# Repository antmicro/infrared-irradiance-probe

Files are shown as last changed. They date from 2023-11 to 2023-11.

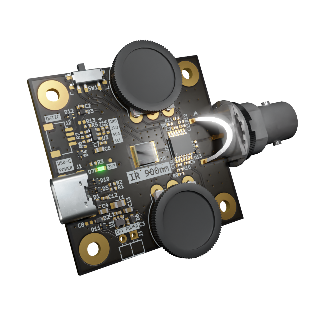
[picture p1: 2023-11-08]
assets/previews/leftT_thumbnail.png

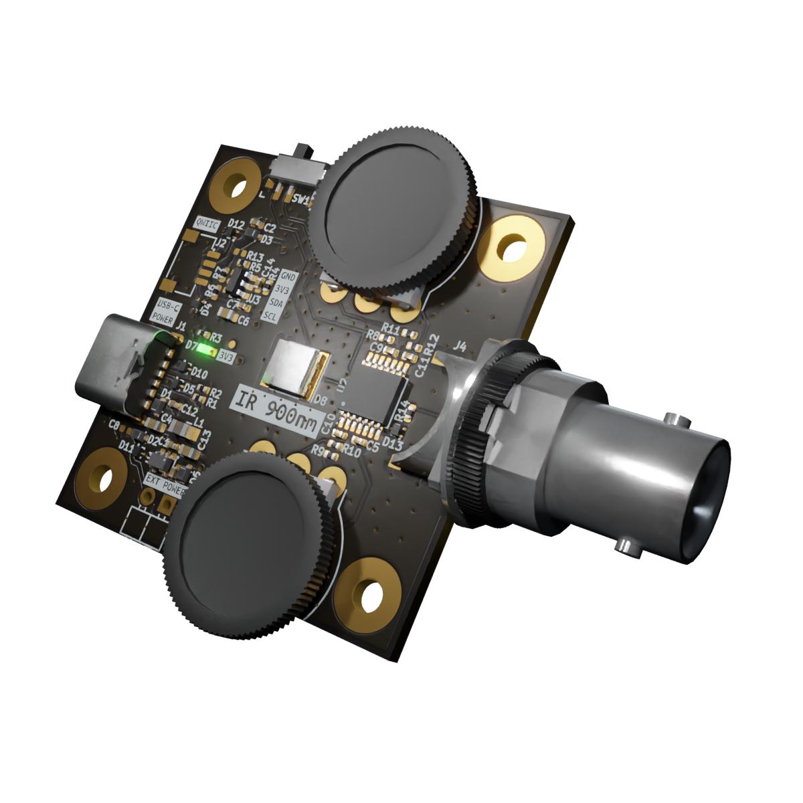
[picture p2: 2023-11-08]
assets/previews/rightT.webp

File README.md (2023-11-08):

# Infrared Irradiance Probe

Copyright (c) 2022-2023 [Antmicro](https://www.antmicro.com)

IR Irradiance Probe

## Overview

This project contains open hardware design files for a simple detector of infrared (IR) radiation.
It features two photodiodes with peak sensitivity of 900nm and 940nm, and signal-forming circuitry with adjustable gain.
The board can be used for measuring relative intensity of IR radiation and for probing dynamic illumination parameters of infrared LEDs and laser modules.

The design files were prepared in KiCad 6.x.

## Project structure 

The main directory contains KiCad PCB design files, a LICENSE and a README.
The remaining files are stored in the following directories: 

* `lib` - contains the component libraries, 
* `img` - contains graphics for this README,
* `assets` - contains visual assets used for showcasing this board on [Open Hardware Portal](https://openhardware.antmicro.com)

## Key features

* Two photodiodes for measuring IR irradiance (peak sensitivity @ 900nm for diode on top and 940nm for the bottom one)
* BNC connector for oscilloscope measurements
* Regulated sensitivity
* I2C single-channel interface for digital signal probing
* Selectable power source (USB-C / JST / external power supply)

## License

This project is licensed under the [Apache-2.0](LICENSE) license.

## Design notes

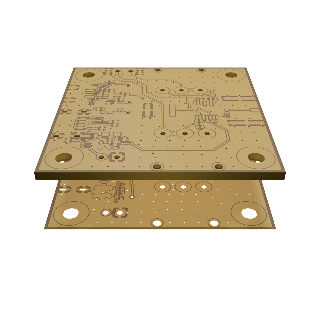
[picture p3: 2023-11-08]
assets/previews/layer1_thumbnail.webp

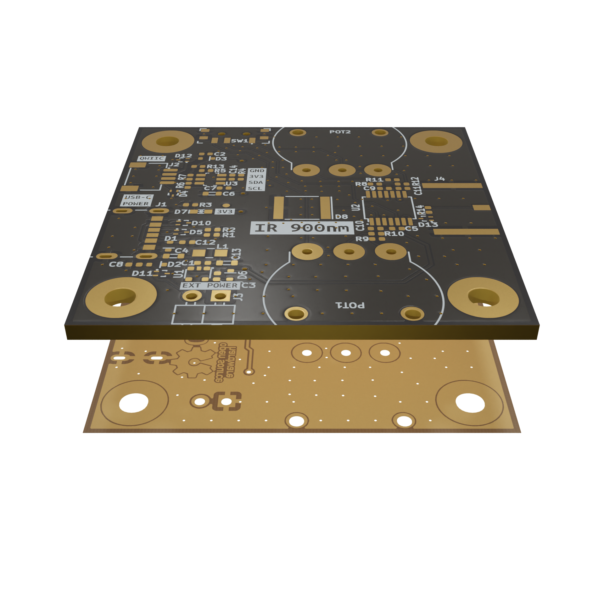
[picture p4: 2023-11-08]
assets/previews/stackup.png

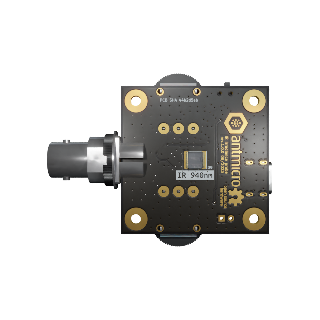
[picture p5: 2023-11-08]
assets/previews/orthoB_thumbnail.webp

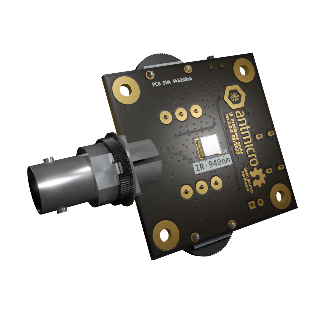
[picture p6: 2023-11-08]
assets/previews/leftB_thumbnail.png

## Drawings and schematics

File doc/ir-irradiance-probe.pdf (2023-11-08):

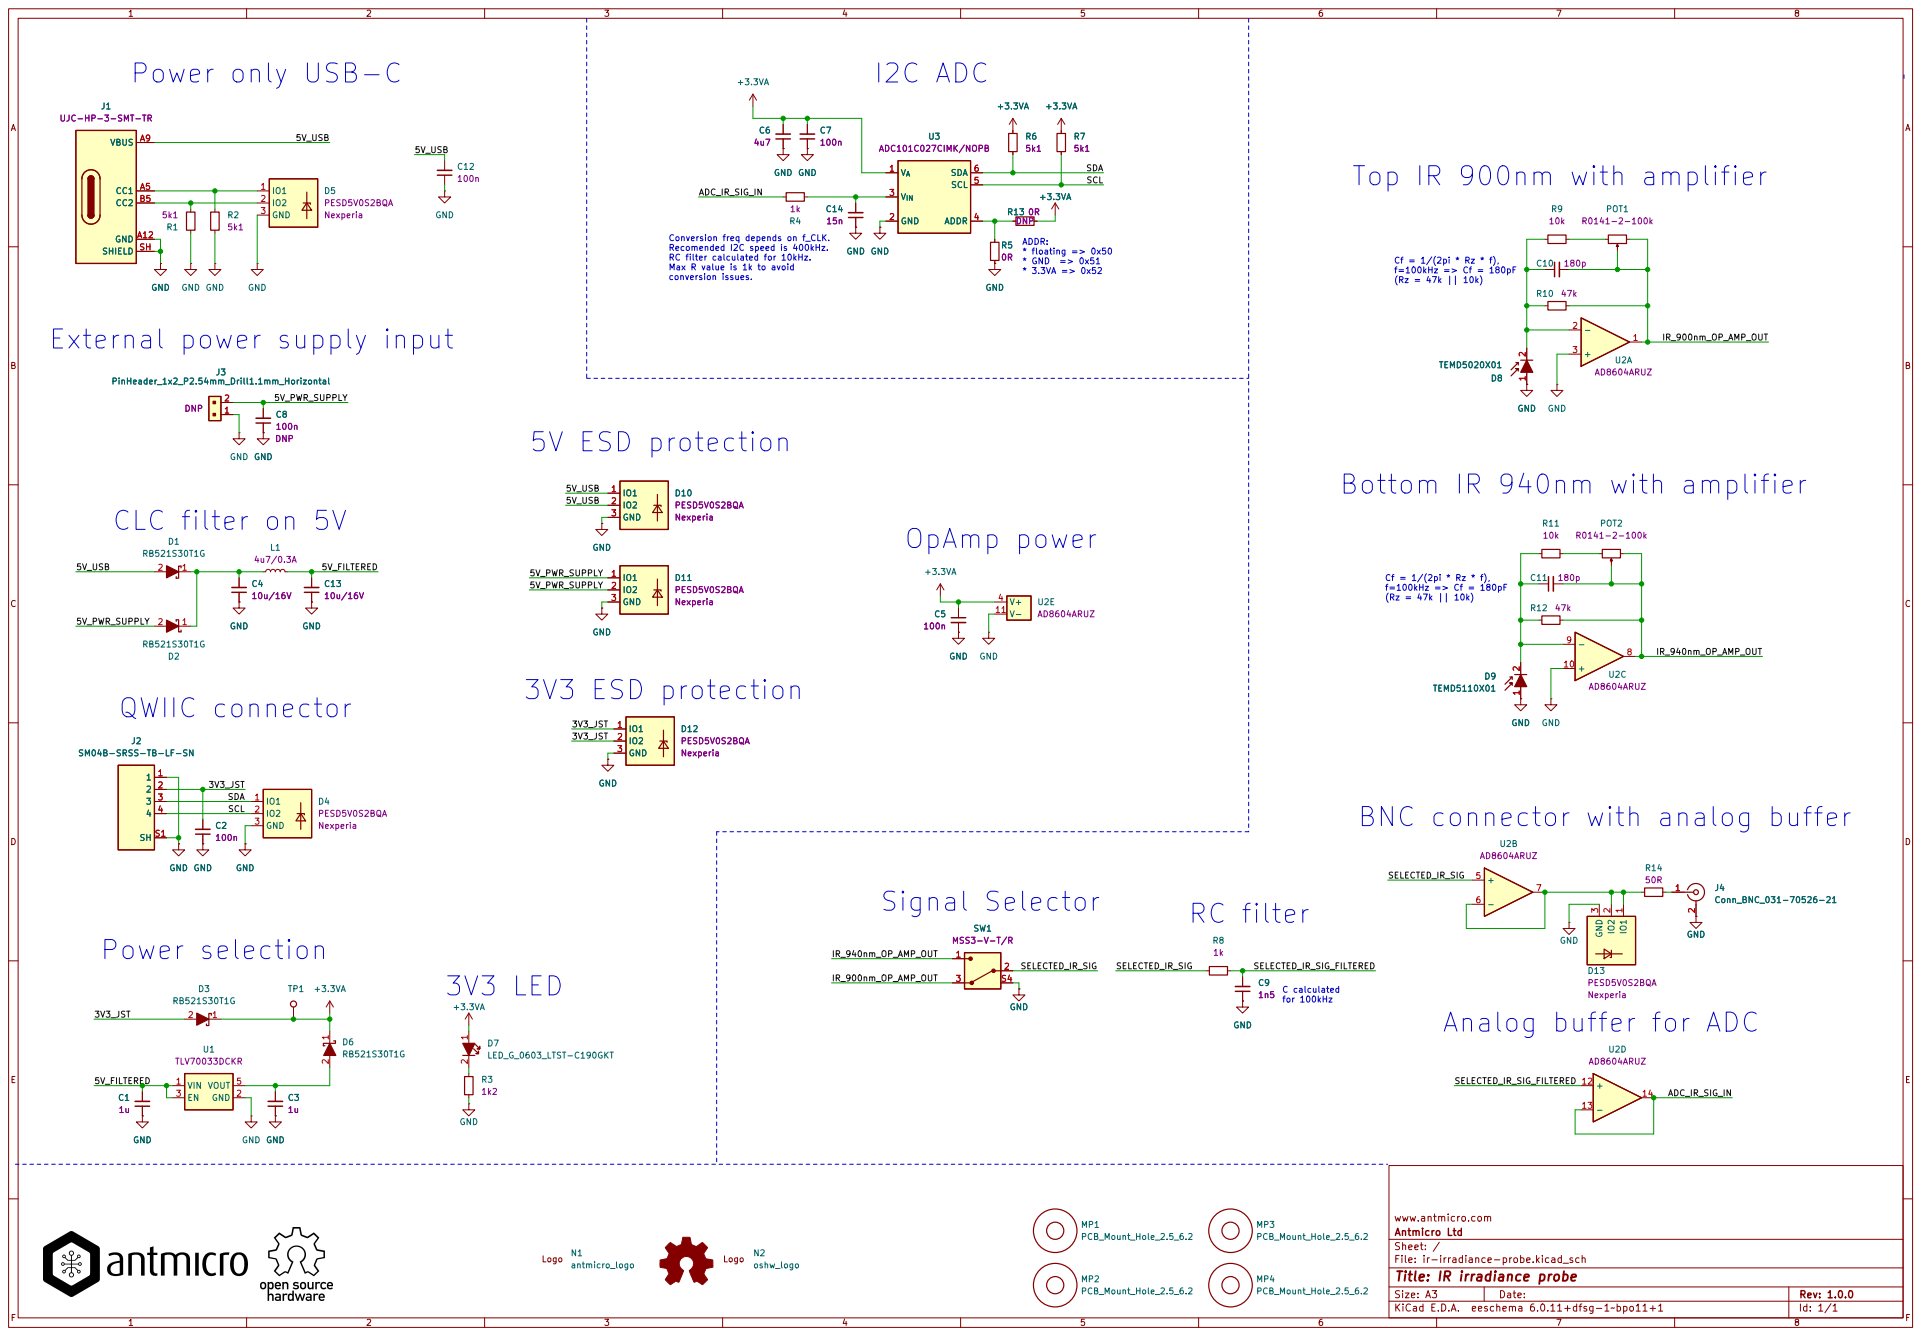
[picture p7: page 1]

J1 UJC-HP-3-SMT-TR

Top IR 900nm with amplifier

Bottom IR 940nm with amplifier

J2 SM04B-SRSS-TB-LF-SN

Id: 1/1 Title: IR irradiance probe

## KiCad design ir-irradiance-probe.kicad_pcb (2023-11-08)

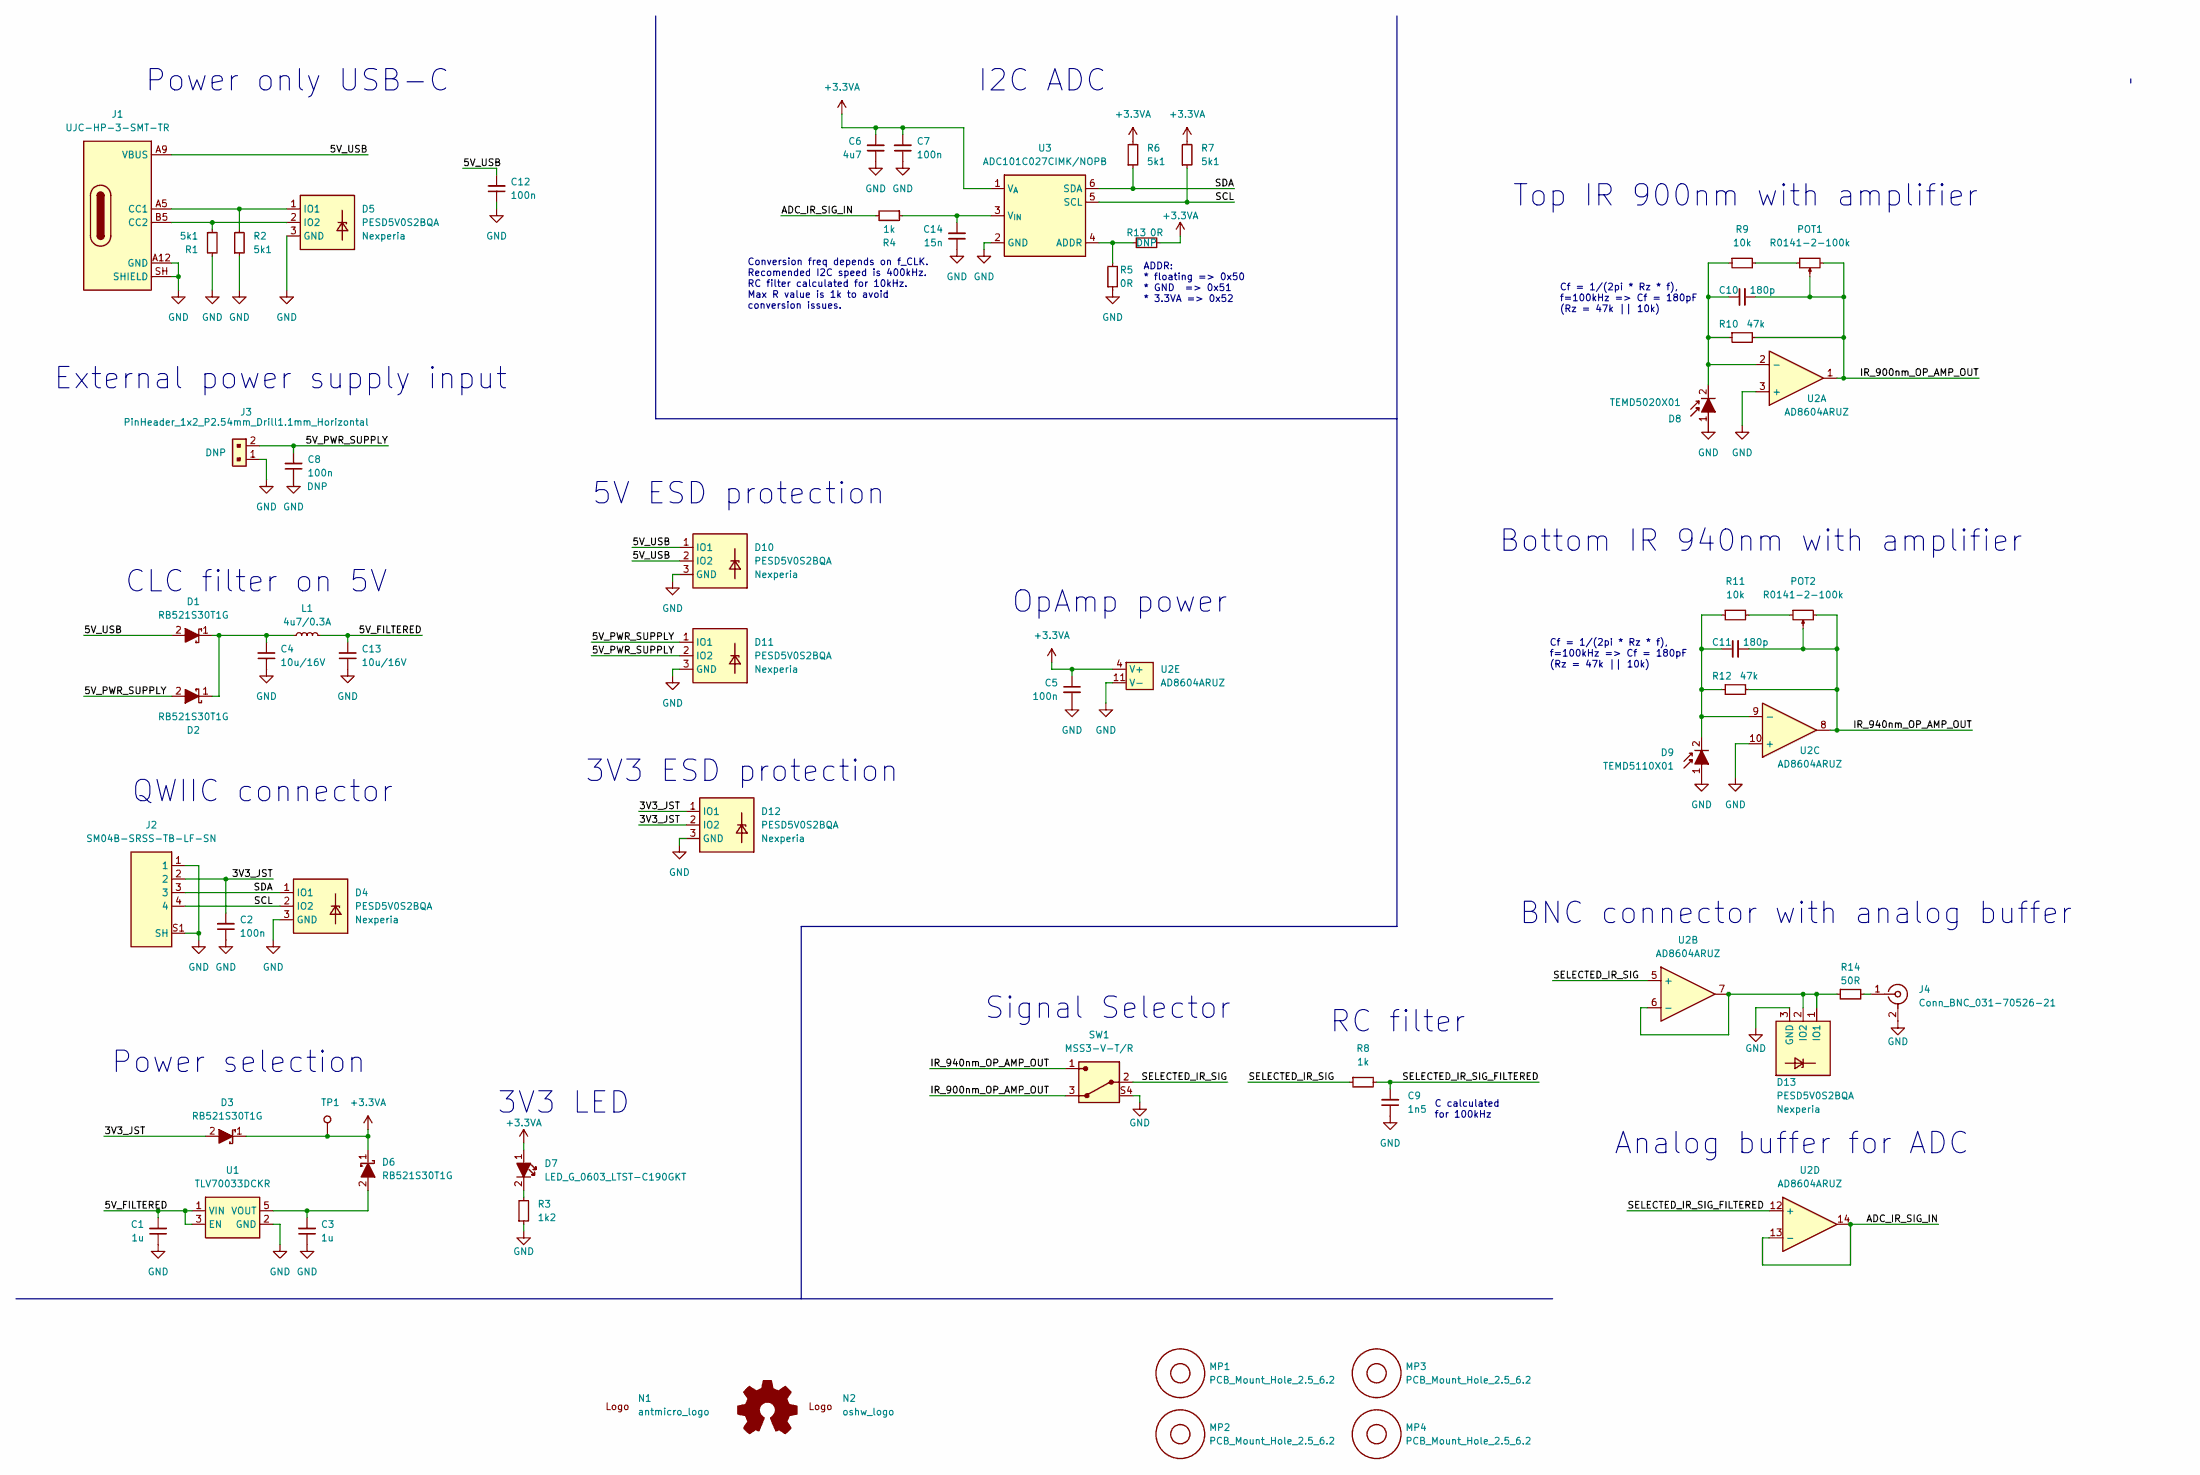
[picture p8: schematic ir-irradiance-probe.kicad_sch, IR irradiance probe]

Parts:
C1, C3: C_1u_0402; C_0402_1005Metric; MPN C1005X6S1A105K050BC
C2, C5, C7, C8, C12: C_100n_0402; C_0402_1005Metric; Voltage 50V; MPN GRM155R61H104KE14D
C4, C13: C_10u_16V_0603; C_0603_1608Metric; MPN GRM188C81C106MA73D
C6: C_4u7_0603; C_0603_1608Metric; MPN C1608X5R1V475M080AC
C9: C_1n5_0402; C_0402_1005Metric; MPN 885012205007
C10, C11: C_180p_0402; C_0402_1005Metric; MPN 04025A181JAT2A
C14: C_15n_0402; C_0402_1005Metric; MPN GRM155R71C153KA01D
D1, D2, D3, D6: RB521S30T1G; SOD-523; MPN RB521S30T1G
D4, D5, D10, D11, D12, D13: PESD5V0S2BQA; TPD2E009DRTR; MPN PESD5V0S2BQA
D7: LED_G_0603_LTST-C190GKT; LED_0603_1608Metric_G; MPN LTST-C190GKT
D8: TEMD5020X01; Photodiode_SMD_4.2x5mm_TEMD; MPN TEMD5020X01
D9: TEMD5110X01; Photodiode_SMD_4.2x5mm_TEMD; MPN TEMD5110X01
J1: USB-C_UJC-HP-3-SMT-TR; MPN UJC-HP-3-SMT-TR
J2: SM04B-SRSS-TB-LF-SN; MPN SM04B-SRSS-TB(LF)(SN)
J3: PinHeader_1x2_P2.54mm_Drill1.1mm_Horizontal; PinHeader_1x02_P2.54mm_Horizontal; MPN 61300211021
J4: Conn_BNC_031-70526-21; MPN 031-70526-21
L1: L_4u7_0.3A_0805; L_0805_2012Metric; MPN MLZ2012M4R7HT000
MP1, MP2, MP3, MP4: PCB_Mount_Hole_2.5_6.2; mounting-hole-2.75mm-M2.5_D6.2mm_PTH
N1: antmicro_logo; antmicro-logo_scaled_20mm
N2: oshw_logo; oshw-logo
POT1, POT2: POT_100k_R0141-2-100k; POT_R0141-2; MPN R0141-2-100k
R1, R2, R6, R7: R_5k1_0402; R_0402_1005Metric; Tolerance 1%; MPN CR0402-FX-5101GLF
R3: R_1k2_0402; R_0402_1005Metric; Tolerance 1%; MPN CR0402-FX-1201GLF
R4, R8: R_1k_0402; R_0402_1005Metric; Tolerance 1%; MPN CR0402-FX-1001GLF
R5, R13: R_0R_0402; R_0402_1005Metric; MPN ERJ2GE0R00X
R9, R11: R_10k_0402; R_0402_1005Metric; Tolerance 1%; MPN CR0402-FX-1002GLF
R10, R12: R_47k_0402; R_0402_1005Metric; Tolerance 1%; MPN CR0402-FX-4702GLF
R14: R_50R_0402; R_0402_1005Metric; Tolerance 1%; MPN CR0402-FX-50R0GLF
SW1: MSS3-V-T_R; Switch_Slide_MSS3; MPN MSS3-V-T/R
TP1: TP_0.75mm_SMD; TP_SMD_0.75mm
U1: TLV70033_SC70; SC-70-5; MPN TLV70033DCKR
U2: AD8604ARUZ; TSSOP-14_4.4x5mm_P0.65mm; MPN AD8604ARUZ
U3: ADC101C027CIMK; SOT-23-6; MPN ADC101C027CIMK/NOPB

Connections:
+3.3VA: C5.1, C6.2, C7.2, D3.1, D6.1, D7.1, R6.2, R7.2, R13.1, TP1.1, U2.4 (V+), U3.1 (V_{A})
/3V3_JST: C2.2, D3.2, D12.1 (IO1), D12.2 (IO2), J2.2
/5V_FILTERED: C1.2, C13.2, L1.2, U1.1 (VIN), U1.3 (EN)
/5V_PWR_SUPPLY: C8.2, D2.2, D11.1 (IO1), D11.2 (IO2), J3.2
/5V_USB: C12.2, D1.2, D10.1 (IO1), D10.2 (IO2), J1.A9 (VBUS), J1.B9 (VBUS)
/ADC_IR_SIG_IN: R4.2, U2.13 (-), U2.14
/IR_900nm_OP_AMP_OUT: C10.2, POT1.2, POT1.3, R10.2, SW1.3, U2.1
/IR_940nm_OP_AMP_OUT: C11.2, POT2.2, POT2.3, R12.2, SW1.1, U2.8
/SCL: D4.2 (IO2), J2.4, R7.1, U3.5 (SCL)
/SDA: D4.1 (IO1), J2.3, R6.1, U3.6 (SDA)
/SELECTED_IR_SIG: R8.1, SW1.2, U2.5 (+)
/SELECTED_IR_SIG_FILTERED: C9.2, R8.2, U2.12 (+)
GND: C1.1, C2.1, C3.1, C4.1, C5.2, C6.1, C7.1, C8.1, C9.1, C12.1, C13.1, C14.1, D4.3 (GND), D5.3 (GND), D8.1, D9.1, D10.3 (GND), D11.3 (GND), D12.3 (GND), D13.3 (GND), J1.A12 (GND), J1.B12 (GND), J1.SH (SHIELD), J2.1, J2.S1 (SH), J2.S2 (SH), J3.1, J4.2, R1.2, R2.1, R3.1, R5.1, SW1.S1 (SH), SW1.S2 (SH), SW1.S3 (SH), SW1.S4 (SH), U1.2 (GND), U2.3 (+), U2.10 (+), U2.11 (V-), U3.2 (GND)
unnamed: C3.2, D6.2, U1.5 (VOUT)
unnamed: C4.2, D1.1, D2.1, L1.1
unnamed: C10.1, D8.2, R9.1, R10.1, U2.2 (-)
unnamed: C11.1, D9.2, R11.1, R12.1, U2.9 (-)
unnamed: C14.2, R4.1, U3.3 (V_{IN})
unnamed: D5.1 (IO1), J1.A5 (CC1), R2.2
unnamed: D5.2 (IO2), J1.B5 (CC2), R1.1
unnamed: D7.2, R3.2
unnamed: D13.1 (IO1), D13.2 (IO2), R14.1, U2.6 (-), U2.7
unnamed: J4.1, R14.2
unnamed: POT1.1, R9.2
unnamed: POT2.1, R11.2
unnamed: R5.2, R13.2, U3.4 (ADDR)

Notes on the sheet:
Signal Selector
CLC filter on 5V
BNC connector with analog buffer
Top IR 900nm with amplifier
ADDR: * floating => 0x50 * GND => 0x51 * 3.3VA => 0x52
RC filter
3V3 ESD protection
Cf = 1/(2pi * Rz * f), f=100kHz => Cf = 180pF (Rz = 47k || 10k)
I2C ADC
Conversion freq depends on f_CLK. Recomended I2C speed is 400kHz. RC filter calculated for 10kHz. Max R value is 1k to avoid conversion issues.
Power only USB-C
Analog buffer for ADC
Power selection
External power supply input
OpAmp power
QWIIC connector
Bottom IR 940nm with amplifier
3V3 LED
5V ESD protection
C calculated for 100kHz

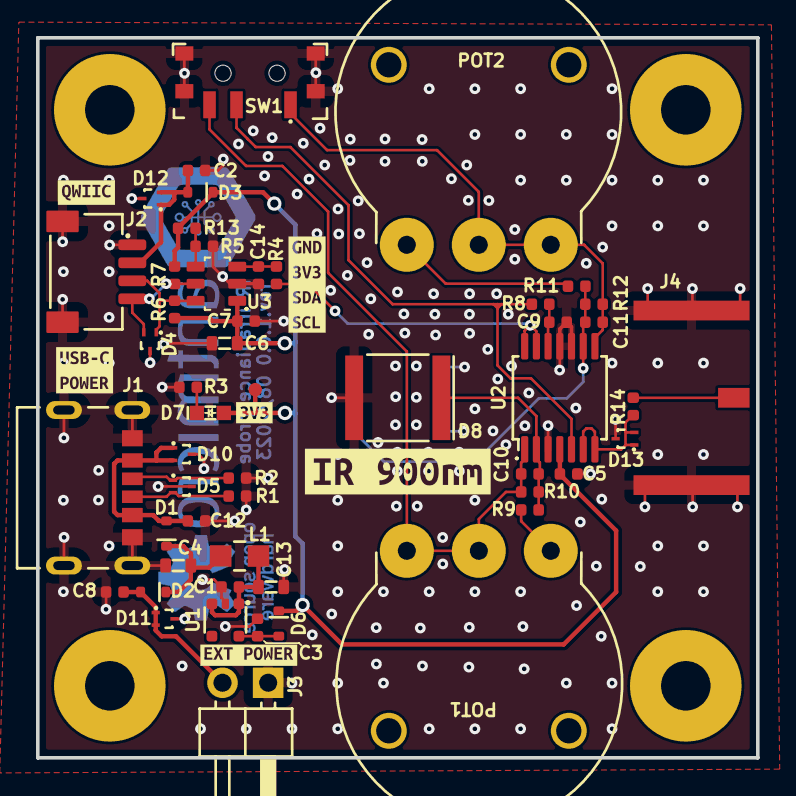
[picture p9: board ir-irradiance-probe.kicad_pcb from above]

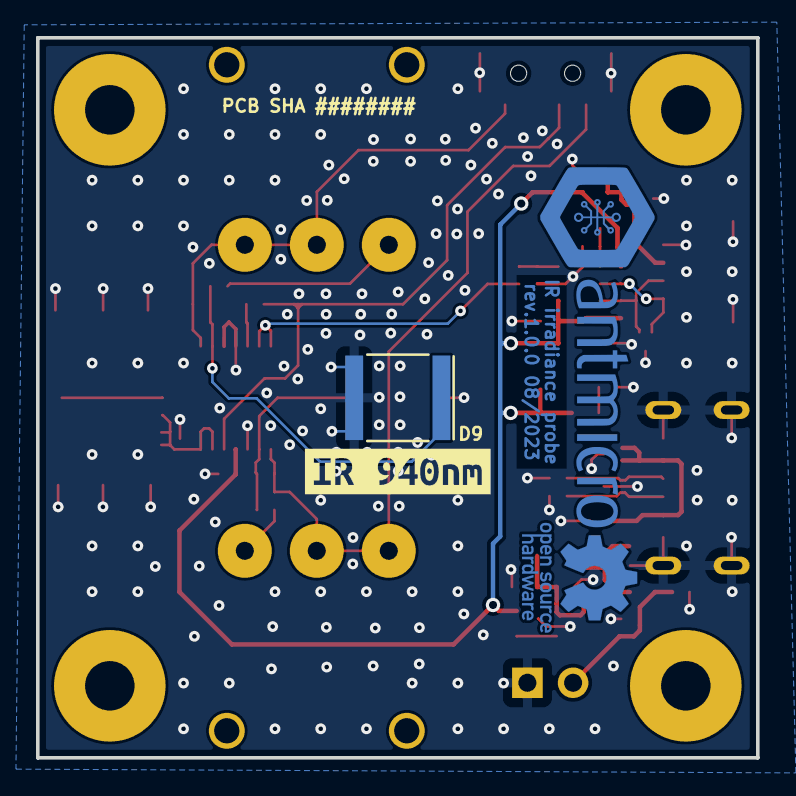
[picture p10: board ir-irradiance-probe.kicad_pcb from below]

Board: 2 copper layers, 40.0 x 40.0 mm, 66 parts (4 on the bottom side), 26 nets.

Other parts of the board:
kibuzzard-64C24E37: G***; kibuzzard-64C24E37
kibuzzard-64C24E46: G***; kibuzzard-64C24E46
kibuzzard-64DA12EE: G***; kibuzzard-64DA12EE
kibuzzard-64DA14BC: G***; kibuzzard-64DA14BC
kibuzzard-64DA143B: G***; kibuzzard-64DA143B
kibuzzard-64DA1325: G***; kibuzzard-64DA1325
kibuzzard-64E321C3: G***; kibuzzard-64E321C3

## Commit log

2023-07-27 [#47284] Create empty kicad project
    [ir-irradiance-probe.kicad_pcb, ir-irradiance-probe.kicad_sch]
2023-07-27 [#47284] Add layout for visual reference and power connectors on sch
    [ir-irradiance-probe.kicad_pcb, ir-irradiance-probe.kicad_sch]
2023-07-27 [#47284] Add ADC and mounting holes on sch
    [ir-irradiance-probe.kicad_sch]
2023-07-28 [#47284] Add analog section to sch
    [ir-irradiance-probe.kicad_sch]
2023-07-28 [#47284] Add power section
    [ir-irradiance-probe.kicad_sch]
2023-08-03 [#47284] Update RC filter with C value
    [ir-irradiance-probe.kicad_sch]
2023-08-03 [#47284] Connect IR signals to the switch
    [ir-irradiance-probe.kicad_sch]
2023-08-03 [#47284] Complete circuit for I2C ADC
    [ir-irradiance-probe.kicad_sch]
2023-08-03 [#47284] Add TVS diodes on USB-C and QWIIC connectors
    [ir-irradiance-probe.kicad_sch]
2023-08-03 [#47284] Add 100n capacitor on OpAmp power pin
    [ir-irradiance-probe.kicad_sch]
2023-08-03 [#47284] Add proper values for CLC filter
    [ir-irradiance-probe.kicad_sch]
2023-08-03 [#47284] Update C values in OpAmp circuit and annotate schematic
    [ir-irradiance-probe.kicad_sch]
2023-08-03 [#47284] Update schematic with symbols from antmicro symlib
    [ir-irradiance-probe.kicad_sch]
2023-08-03 [#47284] Add LED indicator on 3V3 power line
    [ir-irradiance-probe.kicad_sch]
2023-08-07 [#47284] Update potentiometers for amplifiers
    [ir-irradiance-probe.kicad_sch]
2023-08-07 [#47284] Cleaned schematic
    [ir-irradiance-probe.kicad_sch]
2023-08-07 [#47284] Migrated project back to KiCad v6
    [ir-irradiance-probe.kicad_pcb, ir-irradiance-probe.kicad_sch]
2023-08-07 [#47284] Minor fixes in schematic
    [ir-irradiance-probe.kicad_sch]
2023-08-07 [#47284] Prepare preliminary components layout
    [ir-irradiance-probe.kicad_pcb]
2023-08-09 [#47284] Update potentiometer after standardisation
    [ir-irradiance-probe.kicad_pcb, ir-irradiance-probe.kicad_sch]
2023-08-09 [#47284] Create local components library
    [ir-irradiance-probe.kicad_pcb, ir-irradiance-probe.kicad_sch]
2023-08-09 [#47284] Change potentiometers on schematic
    [ir-irradiance-probe.kicad_sch]
2023-08-09 [#47284] Rework PCB layout to fit 4x4cm board
    [ir-irradiance-probe.kicad_pcb]
2023-08-09 [#47284] Change pin header to horizontal
    [ir-irradiance-probe.kicad_pcb, ir-irradiance-probe.kicad_sch]
2023-08-10 [#47284] Mark J3 PinHeader as DNP
    [ir-irradiance-probe.kicad_sch]
2023-08-10 [#47284] Change bottom photodiode from TEMD5020X01 to TEMD5110X01
    [ir-irradiance-probe.kicad_pcb, ir-irradiance-probe.kicad_sch]
2023-08-10 [#47284] Unified text size on schematic
    [ir-irradiance-probe.kicad_sch]
2023-08-10 [#47284] Update project info and add logo
    [ir-irradiance-probe.kicad_sch]
2023-08-10 [#47284] Update USB circuit
    [ir-irradiance-probe.kicad_sch]
2023-08-10 [#47284] Update PinHeader circuit
    [ir-irradiance-probe.kicad_sch]
2023-08-10 [#47284] Update JST circuit
    [ir-irradiance-probe.kicad_sch]
2023-08-10 [#47284] Fixed 3V3 LED circuit
    [ir-irradiance-probe.kicad_sch]
2023-08-10 [#47284] Updated RC filter on ADC input line
    [ir-irradiance-probe.kicad_sch]
2023-08-10 [#47284] Updated CLC filter on 5V line
    [ir-irradiance-probe.kicad_sch]
2023-08-10 [#47284] Add ESD protection on BNC connector
    [ir-irradiance-probe.kicad_sch]
2023-08-10 [#47284] Annotated components and reorganised schematic
    [ir-irradiance-probe.kicad_sch]
2023-08-10 [#47284] Updated PCB layout
    [ir-irradiance-probe.kicad_pcb, ir-irradiance-probe.kicad_sch]
2023-08-10 [#47284] Run kmake loclib
    [ir-irradiance-probe.kicad_pcb, ir-irradiance-probe.kicad_sch]
2023-08-14 [#47284] Standardized the rest of the components
    [ir-irradiance-probe.kicad_pcb, ir-irradiance-probe.kicad_sch]
2023-08-14 [47284] Set stackup and constraints
    [ir-irradiance-probe.kicad_pcb]
2023-08-14 [47284] Add preliminary routing
    [ir-irradiance-probe.kicad_pcb, ir-irradiance-probe.kicad_sch]
2023-08-14 [47284] Clear DRC errors and warnings
    [ir-irradiance-probe.kicad_pcb]
2023-08-14 [47284] Add pcb sha string
    [ir-irradiance-probe.kicad_pcb]
2023-08-14 [47284] Add connectors labels
    [ir-irradiance-probe.kicad_pcb]
2023-08-18 [#47284] Fix antmicro and ohw logos positioning
    [ir-irradiance-probe.kicad_pcb]
2023-08-18 [#47284] Fix routing
    [ir-irradiance-probe.kicad_pcb]
2023-08-18 [#47284] Changed stackup to EC_2_Layers_Standard
    [ir-irradiance-probe.kicad_pcb]
2023-08-18 [#47284] Add copper plane on bottom layer
    [ir-irradiance-probe.kicad_pcb]
2023-08-18 [#47284] Add vias on 2.54mm grid
    [ir-irradiance-probe.kicad_pcb]
2023-08-18 [#47284] Fix potentiometer labels position
    [ir-irradiance-probe.kicad_pcb]
2023-08-21 [#47284] Add 50R resistor on BNC connector
    [ir-irradiance-probe.kicad_pcb, ir-irradiance-probe.kicad_sch]
2023-08-21 [#47284] Remove DNP attribute from C10 and C11
    [ir-irradiance-probe.kicad_pcb, ir-irradiance-probe.kicad_sch]
2023-08-21 [#47284] Add label and TestPoint near 3V3 LED
    [ir-irradiance-probe.kicad_pcb, ir-irradiance-probe.kicad_sch]
2023-11-08 [#47284] Update footprint for SW1, add OHP assets
    [ir-irradiance-probe.kicad_pcb, stackup.csv]

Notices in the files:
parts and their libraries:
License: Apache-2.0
